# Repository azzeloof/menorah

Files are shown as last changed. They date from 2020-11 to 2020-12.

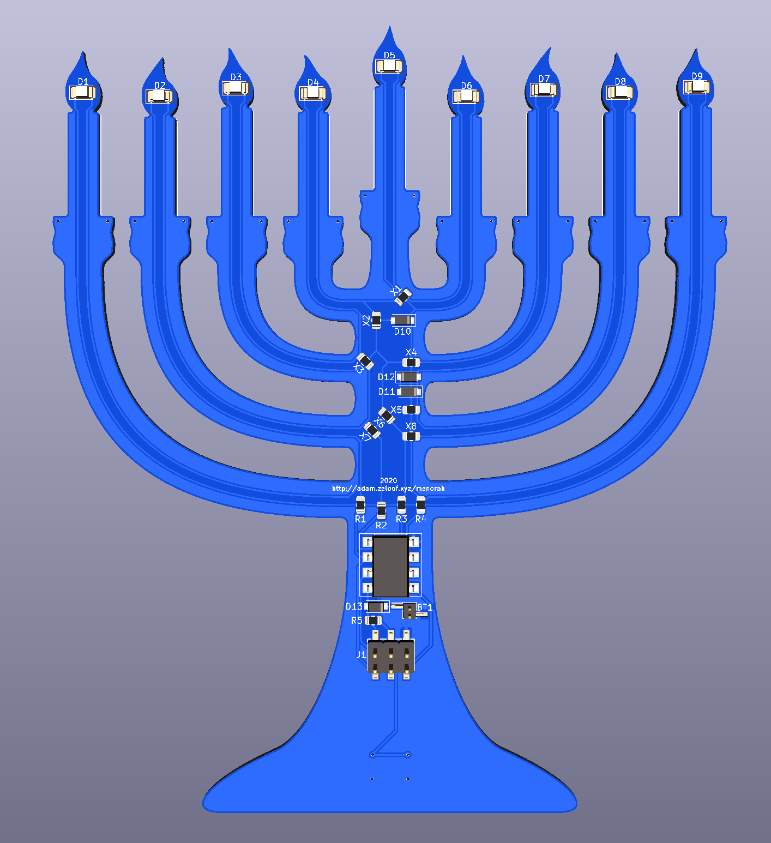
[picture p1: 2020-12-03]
hardware/menorah_pcb_front.png

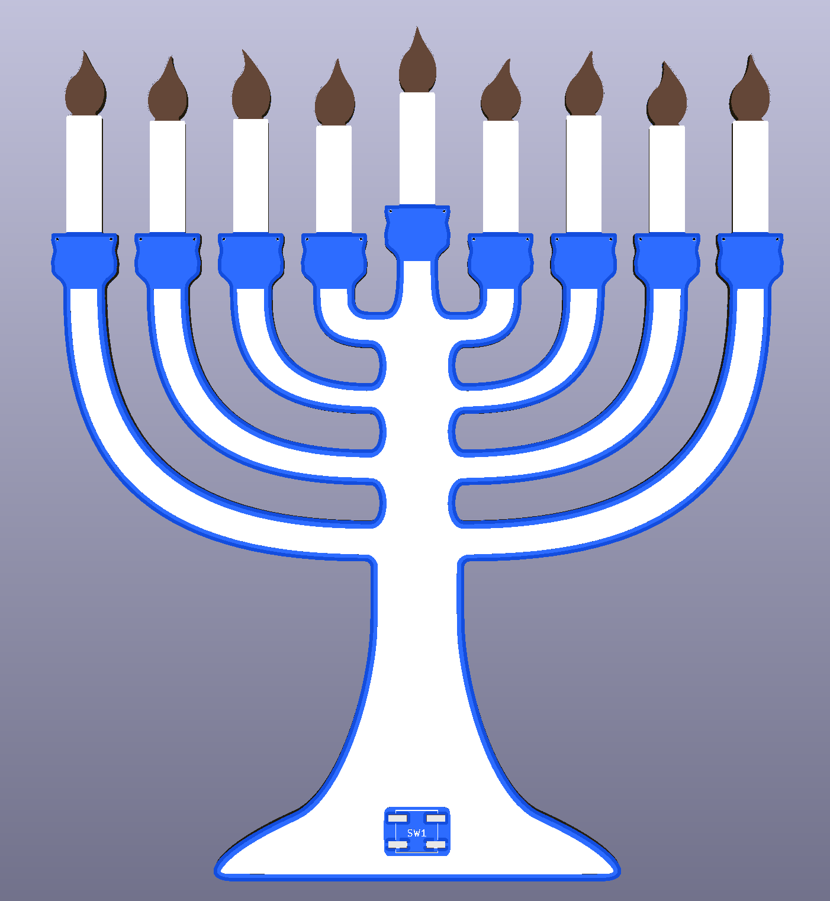
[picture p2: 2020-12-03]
hardware/menorah_pcb_back.png

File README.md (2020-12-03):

# menorah
A PCB menorah!
This is a work in progress, though I've ordered boards so I hope the hardware is correct. The majority of the circuit is copied from [the snowflake ornament I worked on last year](https://github.com/azzeloof/snowflake), but some parts of this circuit (the pinout of the programming header) are untested.

PCB aside, the total component cost comes to less than $10. You'll need an AVR programmer too (though I think you can use an Arduino).

Firmware will be added soon. I wanted to post this as soon as I finished the hardware in case anybody wants to make one in time for Hanukkah!

# hardware
*BOM Change* I made a mistake in the board layout. For the ATTiny85, I used the same footprint I used on the snowflake, which is a SMD footprint for a DIP-8 socket. I should have used a SOIC-8 footprint to accommodate the SMD ATTiny85 I chose. The BOM has been updated to include a socket and THT ATTiny85. The other (and probably better) approach would be to update the board layout to use the correct footprint.
The board is a sample two-layer PCB. I ordered from PCBWay, because they'll make boards with a blue solder mask and white siklscreen. I used lead-free HASL as a copper finish. Immersion silver might look good too, though it's expensive, it can tarnish, and takes longer to produce. Honestly I woulda probably gone with it if lead time wasn't an issue.
ENIG or hard gold would look good too if you'd rather go for that look.

If you want to make your own, you can take the gerbers from the hardware directory.
It can be [directly ordered from PCBWay](https://www.pcbway.com/project/shareproject/LED_Menorah.html) also.

Controller is an ATtiny85, and power comes from a AAA battery pack that gets adhered to the back (it also acts as a support). LEDs are reverse-mounted to shine through the board. Resistor values in the schematic are set for blue LEDs, but I'll probably change them to red or yellow. Use whichever colors you'd like, just make sure to set the resistors appropriatley. 

# firmware
coming soon

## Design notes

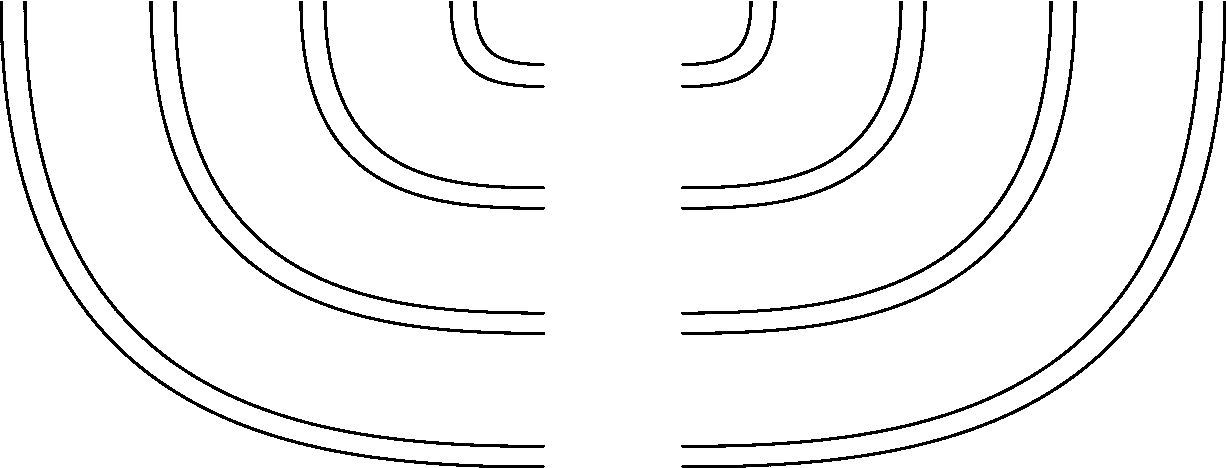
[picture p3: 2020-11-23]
hardware/artwork/menorah_traces.png

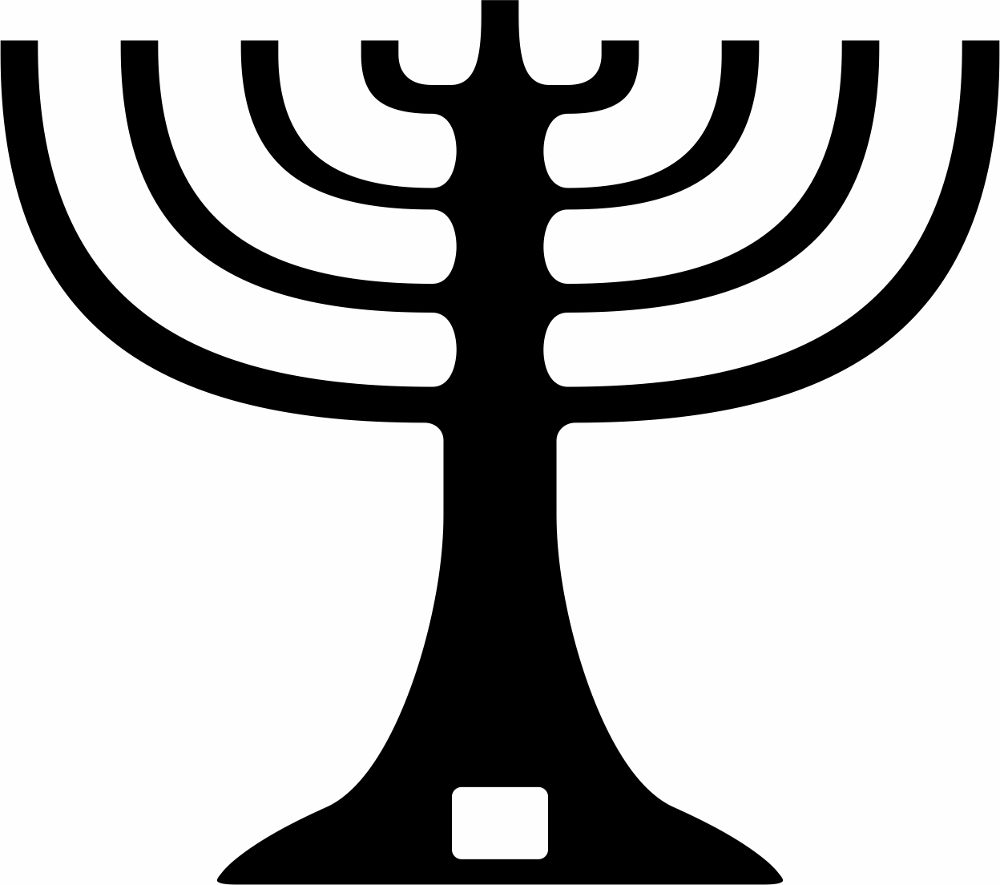
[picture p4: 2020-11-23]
hardware/artwork/menorah-mask.jpg

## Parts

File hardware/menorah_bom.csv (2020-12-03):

Manufacturer Part Number | Manufacturer | Digi-Key Part Number | Customer Reference | Reference Designator | Packaging | Part Status | Quantity | Unit Price | Extended Price | Quantity Available | Mfg Std Lead Time | Description | RoHS Status | Lead Free Status | REACH Status
RC0805FR-074K7L | Yageo | 311-4.70KCRCT-ND | R5 |  | Cut Tape (CT) | Active | 1 | 0.10000 | $0.10 | 1679994 | 24 Weeks | RES SMD 4.7K OHM 1% 1/8W 0805 | ROHS3 Compliant | Lead free | REACH Unaffected
PTS645SL50SMTR92 LFS | C&K | CKN9088CT-ND | SW1 |  | Cut Tape (CT) | Active | 1 | 0.25000 | $0.25 | 99873 | 14 Weeks | SWITCH TACTILE SPST-NO 0.05A 12V | ROHS3 Compliant | Lead free | REACH Unaffected
SM4004PL-TP | Micro Commercial Co | SM4004PL-TPMSCT-ND | D10, D11, D12, D13 |  | Cut Tape (CT) | Active | 4 | 0.43000 | $1.72 | 36149 | 12 Weeks | DIODE GEN PURP 400V 1A SOD123FL | ROHS3 Compliant | Lead free | REACH Unaffected
RMCF0805ZT0R00 | Stackpole Electronics Inc | RMCF0805ZT0R00CT-ND | X1, X2, X3, X4, X5, X6, X7, X8 |  | Cut Tape (CT) | Active | 8 | 0.10000 | $0.80 | 1034801 | 20 Weeks | RES 0 OHM JUMPER 1/8W 0805 | ROHS3 Compliant | Lead free | REACH Unaffected
4191 | Adafruit Industries LLC | 1528-2948-ND | BT1 |  | Bulk | Active | 1 | 1.95000 | $1.95 | 141 | Not Available | 2 X AAA BATTERY HOLDER WITH ON/O | Vendor undefined | Not Available | Not Available
APTR3216SYCK | Kingbright | 754-1174-1-ND | D1, D2, D3, D4, D5, D6, D7, D8, D9 |  | Cut Tape (CT) | Active | 9 | 0.31000 | $2.79 | 84152 | 12 Weeks | LED YELLOW CLEAR CHIP SMD | ROHS3 Compliant | Lead free | REACH Unaffected
RMCF0805FT51R0 | Stackpole Electronics Inc | 738-RMCF0805FT51R0CT-ND | R1, R2, R3, R4 |  | Cut Tape (CT) | Active | 4 | 0.10000 | $0.40 | 14430 | 20 Weeks | RES 51 OHM 1% 1/8W 0805 | ROHS3 Compliant | Lead free | REACH Unaffected
3020-06-0300-00 | CNC Tech | 1175-1864-ND | J1 |  | Tray | Active | 1 | 0.48000 | $0.48 | 2160 | 18 Weeks | CONN HEADER SMD 6POS 2.54MM | ROHS3 Compliant | Lead free | REACH Unaffected
114-87-308-41-134161 | Preci-Dip | 1212-1032-ND | U1 |  | Tube | Active | 1 | 0.57000 | $0.57 | 7320 | 15 Weeks | CONN IC DIP SOCKET 8POS GOLD | ROHS3 Compliant | Lead free | REACH Unaffected
ATTINY85-20PU | Microchip Technology | ATTINY85-20PU-ND | U1 |  | Tube | Active | 1 | 1.20000 | $1.20 | 4688 | 25 Weeks | IC MCU 8BIT 8KB FLASH 8DIP | ROHS3 Compliant | Lead free | REACH Unaffected

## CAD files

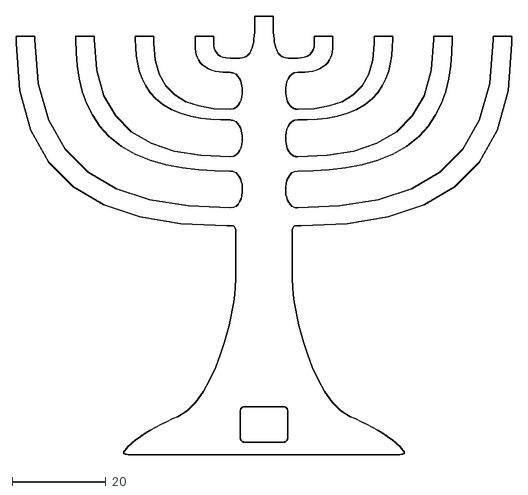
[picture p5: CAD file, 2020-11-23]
hardware/artwork/menorah-mask.dxf
105.5 x 93.4

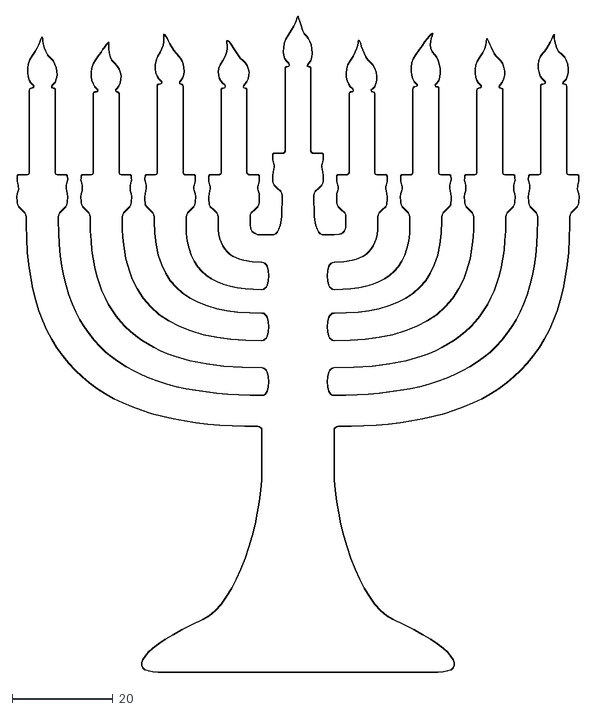
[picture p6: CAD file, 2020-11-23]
hardware/artwork/menorah-inkscape.dxf
111.8 x 130.3

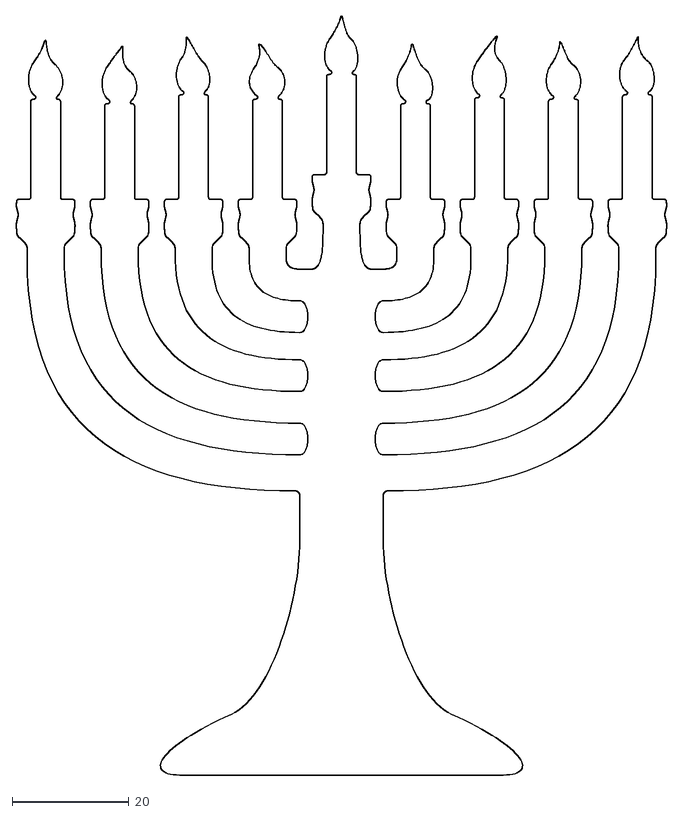
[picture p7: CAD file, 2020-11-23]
hardware/artwork/menorah-inkscape-freecad.dxf
111.6 x 130.3

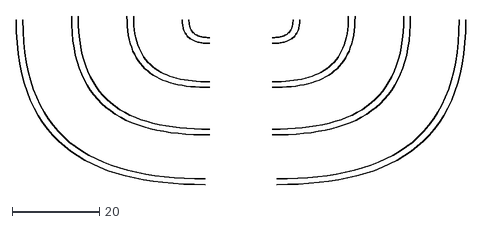
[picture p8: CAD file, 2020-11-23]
hardware/artwork/menorah_traces.dxf
103.1 x 38.5

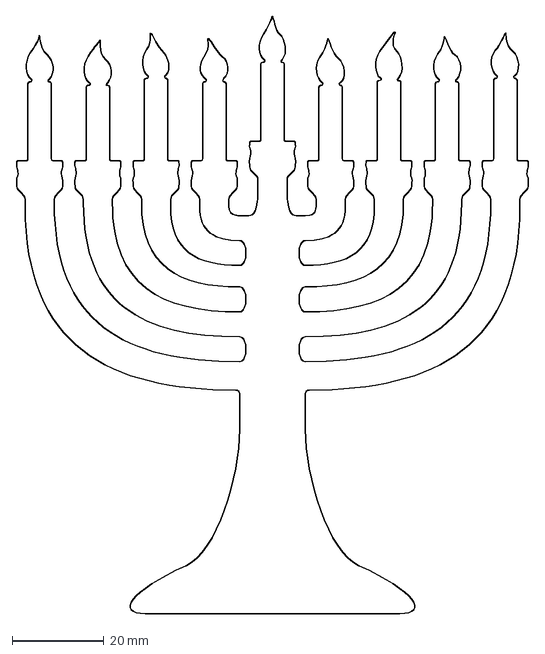
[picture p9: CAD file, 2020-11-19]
hardware/artwork/menorah.dxf
111.9 x 130.3 mm

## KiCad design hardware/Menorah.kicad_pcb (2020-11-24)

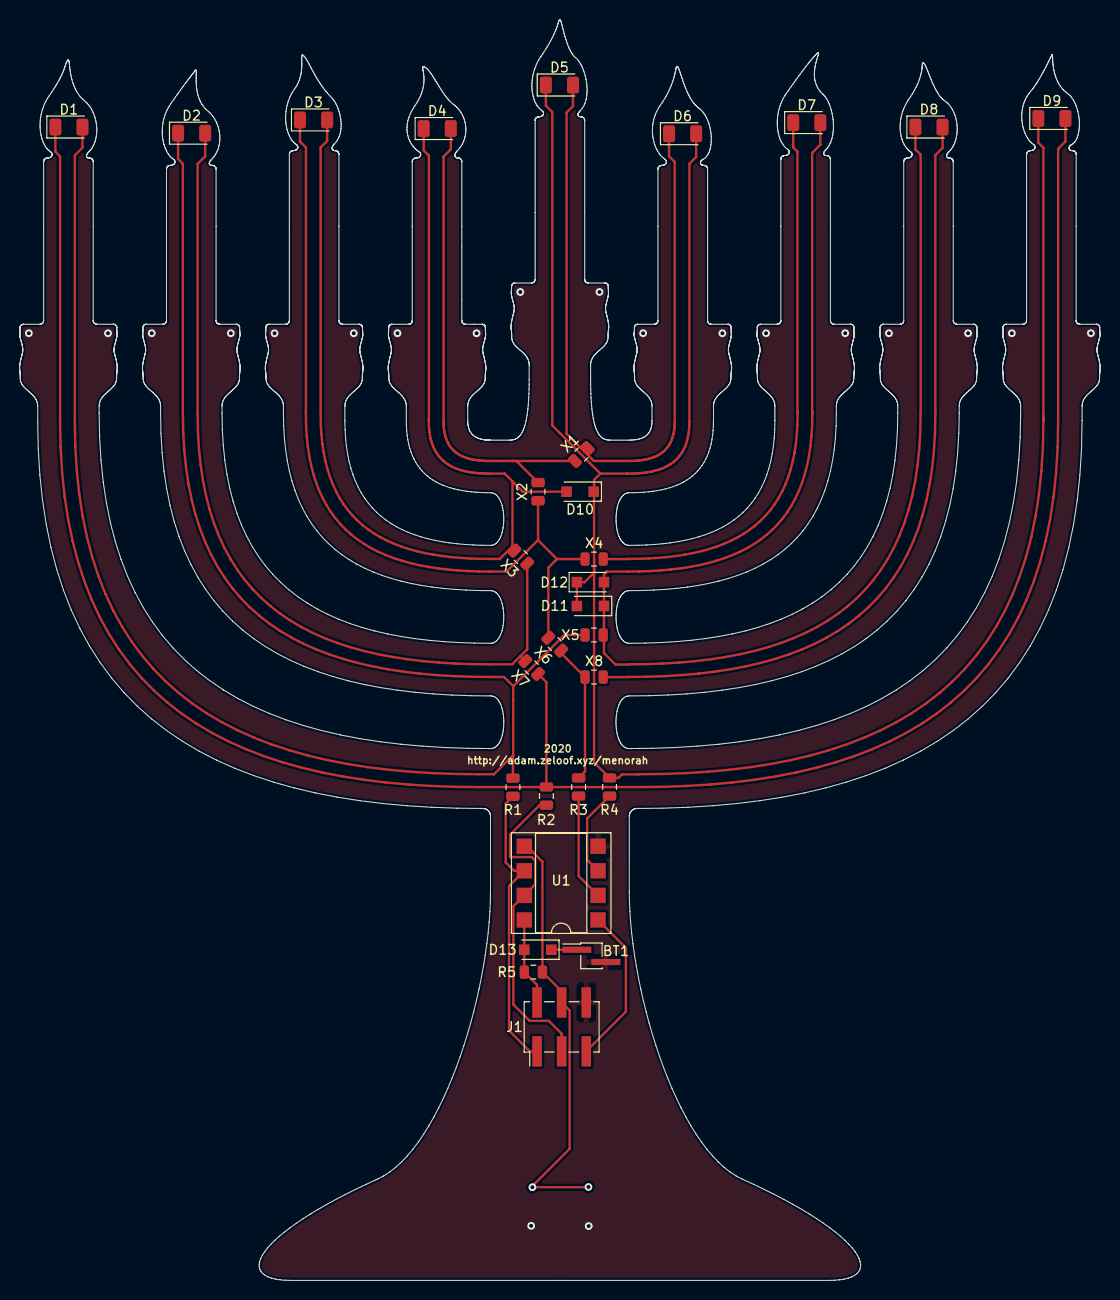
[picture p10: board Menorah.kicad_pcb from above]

Board: 2 copper layers, 111.6 x 130.3 mm, 30 parts (1 on the bottom side), 13 nets.

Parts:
BT1: Battery; PinHeader_1x02_P1.27mm_Vertical_SMD_Pin1Left
D1, D2, D3, D4, D5, D6, D7, D8, D9: LED; LED_1206_3216Metric
D10, D11, D12, D13: 1N4004; D_SOD-123F
J1: Conn_02x03_Odd_Even; PinHeader_2x03_P2.54mm_Vertical_SMD
R1, R2, R3, R4: 68; R_0805_2012Metric
R5: 4k7; R_0805_2012Metric
SW1: SW_Push; SW_Push_1P1T_NO_CK_KSC6xxJ
U1: ATtiny85-20PU; DIP-8_W7.62mm_SMDSocket_SmallPads
X1, X2, X3, X4, X5, X6, X7, X8: R_0805_2012Metric

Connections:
GND: BT1.2, J1.6, SW1.2, U1.4
MISO: J1.1, R1.2, U1.6
MOSI: J1.4, R5.1, SW1.1, U1.5
unnamed: BT1.1, D13.1
unnamed: D1.1, D2.2, D3.2, D4.1, D9.2, D10.2, R2.1, X3.1, X3.2, X7.1, X7.2
unnamed: D1.2, D2.1, D7.2, D8.1, D11.1, D12.2, R1.1, X5.1, X5.2
unnamed: D3.1, D4.2, D5.2, D6.1, D7.1, D8.2, R3.1, X1.1, X1.2, X2.1, X2.2, X4.1, X4.2, X6.1, X6.2, X8.1, X8.2
unnamed: D5.1, D6.2, D9.1, D10.1, D11.2, D12.1, R4.1
unnamed: R3.2, U1.2
unnamed: R4.2, U1.3
RST: J1.5, U1.1
SCK: J1.3, R2.2, U1.7
VCC: D13.2, J1.2, R5.2, U1.8

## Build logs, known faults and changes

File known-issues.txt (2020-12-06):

Known Issues
(Things I screwed up)
Last updated 12/5/2020

This is what happens when I copy one of my old schematics without thinking about it enough. Props to sam for finding most of the issues.

- ATTiny85 foorprint is wrong (changed BOM, added socket)
- Power supply is 3V, designed for 6V. Solution is to shrot across D13 (its purpose was to drop the voltage by ~0.7v), and replace R1, R2, R3, R4 with 0-Ohm jumpers. Current is low enough to nor rewuire the current limiting resistors.
- Diodes D10, D11, and D12 have a lower forward voltage than the LEDs. This creates a sneaky current path, and soe of the LEDs ton;t turn on. Solution is to omit D10, D11 and D12. I probably shouldn't even have included them in the design.

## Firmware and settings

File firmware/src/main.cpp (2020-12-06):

/*
 * PCB Menorah
 * 
 * Adam Zeloof and Sara Adkins - December 2020
 * 
 * PWM code adapted from David Johnson-Davies - www.technoblogy.com - 19th February 2017
 * http://www.technoblogy.com/show?2H0K
 */

#include "Arduino.h"
#include "modeButton.h"
#include "leds.h"

// Timer/Counter1 overflow interrupt
ISR(TIM1_COMPA_vect) {
  static uint8_t row, ramp, column, bits, colbit;
  ramp = (ramp+1) & 0x3F;             // Count from 0 to 63
  if (ramp == 0) {
    bits = 0x07; //0000111                    // All on
    column = (column + 1) & 0x03; // Count from 0 to 3
    row = column * 3;               //0 3 6 9
    colbit = 1<<(column+0); // 0b0001 0b0010 0b0100 0b1000
  }

  //check if check col has reached its ramp
  if (Level[row] == ramp) bits = bits & 0x06; // 00000110, mask out pos 0
  if (Level[row+1] == ramp) bits = bits & 0x05; // 00000101, mask out pos 1
  if (Level[row+2] == ramp) bits = bits & 0x03; // 00000011, mask out pos 2
  
  uint8_t mask = colbit - 1; 
  
  uint8_t outputs = (bits & mask) | (bits & ~mask)<<1;
  DDRB = (outputs | colbit) << 1;
  PORTB = (outputs) << 1;
}

uint8_t baseBrightness = 50;
uint8_t maxBrightness = 63;
uint8_t candleLevels[NUM_LEDS];
uint8_t candleFadeCounter[NUM_LEDS];
uint8_t candleFadeInit = 32;
uint8_t variability = 3;
uint8_t day = 0;
uint8_t flickerDelay = 50;
uint32_t oldMillis = 0;

void setup() {
  // Set up Timer/Counter1 to multiplex the LEDs
  TCCR1 = 1<<CTC1 | 2<<CS10;          // Divide by 2
  GTCCR = 0;                          // No PWM
  OCR1A = 0;
  OCR1C = 250-1;                      // 16kHz
  TIMSK = TIMSK | 1<<OCIE1A;          // Compare Match A interrupt

  setupButton();
  setupLeds();

  for(int i=0; i<NUM_LEDS; i++) {
    candleFadeCounter[i] = candleFadeInit;
  }
}

void loop () {
  srand(millis());
  oldMillis = millis();
  for(int i=0; i<day; i++) {
    if(candleLevels[i] < baseBrightness) {
      candleLevels[i] = LogLevels[candleFadeCounter[i]];
      candleFadeCounter[i]++;
    } else {
      candleLevels[i] += ((rand() % variability) - variability/2);
      if(candleLevels[i] < baseBrightness) {
        candleLevels[i] = baseBrightness;
      } else if (candleLevels[i] > maxBrightness){
        candleLevels[i] = maxBrightness;
      }
    }
    setLed(i, candleLevels[i]);
  }
  while(millis() < oldMillis + flickerDelay) {
    if(checkButton()){
      if(day < NUM_LEDS) {
        day ++;
      } else {
        day = 1;
        clearLeds();
        for(int i=0; i<NUM_LEDS; i++) {
          candleLevels[i] = 0;
          candleFadeCounter[i] = candleFadeInit;
        }
      }
      break;
    }
  }
  oldMillis = millis();
}

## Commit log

2020-11-19 Initial PCB artwork
    [Menorah.kicad_pcb, Menorah.sch, menorah.dxf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]
2020-11-19 updated schematic
    [Menorah.sch]
2020-11-19 assigned footprints, started layout
    [Menorah.kicad_pcb, Menorah.sch]
2020-11-20 placement progress
    [Menorah.kicad_pcb]
2020-11-23 lotsa stuff
    [#menorah.dxf, #menorah_traces.dxf, Menorah.kicad_pcb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]
2020-11-24 layout progress
    [Menorah.kicad_pcb]
2020-11-24 fixed ground planes
    [Menorah.kicad_pcb]
2020-11-24 Finished (?) layout, ordered boards.
    [#menorah.dxf, #menorah_traces.dxf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]
2020-11-25 Added BOM
    [Menorah.sch]
2020-12-01 Updated BOM to fix footprint mistake
    [menorah_bom.csv]
